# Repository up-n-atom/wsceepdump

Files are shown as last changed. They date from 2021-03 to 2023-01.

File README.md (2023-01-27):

# Just Enough WonderSwan Color/Swan Crystal EEPROM dumper

_⚠️ USE WITH CAUTION! Always test on a handheld of lesser importance to confirm its operation_

On each boot the bootrom writes to the EEPROM, removing the authenticity of the factory default. Such writes include the _"unique"_ cartridge count, boot count, and previously booted cartridge identifier. If these are not important, a custom rom and serial cable is the more convenient alternative, eg. https://github.com/asiekierka/ws-ieepview

> Fun Fact: The SwanCrystal EEPROM contains the Bandai bootsplash present in the bootrom.

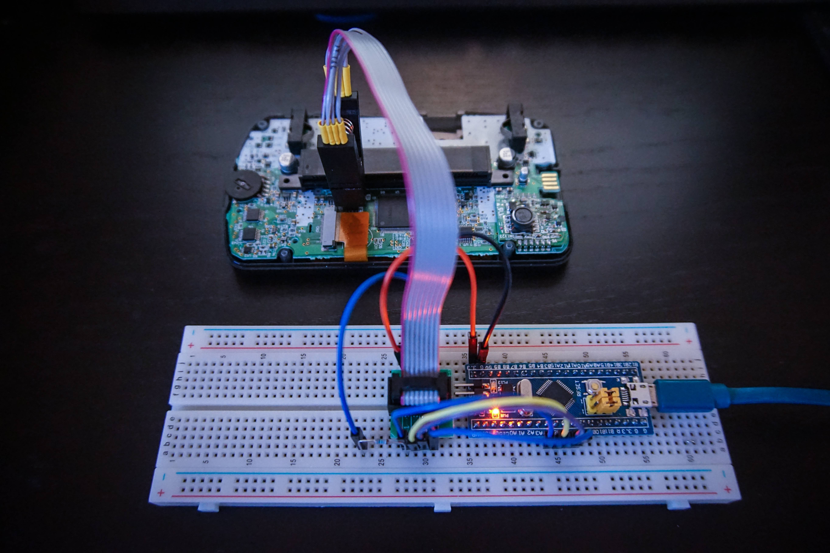
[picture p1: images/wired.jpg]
Wired


## Components

> Shop around, AliExpress links are non-affiliated top searches.

* 1x Blue Pill [[AliExpress](https://www.aliexpress.com/item/32792513237.html)]
* 1x ST-Link<sup>1</sup> or USB to TTL<sup>2</sup> [[AliExpress<sup>1</sup>](https://www.aliexpress.com/item/32887597480.html) or [AliExpress<sup>2</sup>](https://www.aliexpress.com/item/32946781917.html)]
* 1x SOP8 Test Clip [[AliExpress](https://www.aliexpress.com/item/32968334401.html)]
* 1x Breadboard [[AliExpress](https://www.aliexpress.com/item/32430469610.html)]
* 7x Male to Male Dupont Cables [[AliExpress](https://www.aliexpress.com/item/4000203371860.html)]
* 1x 1.2K Resistor [[AliExpress](https://www.aliexpress.com/item/32847096736.html)]

## Arduino Bootloader

There are nemerous guides on how to install the STM32duino bootloader and the following [video](https://www.youtube.com/watch?v=Myon8H111PQ) does an excellent job of describing the process.

How to Install the STM32 USB Bootloader, New Version! \(Blue Pill F103C8T6\) (https://www.youtube.com/watch?v=Myon8H111PQ)

Additionally, you may require the [STM32 Virtual COM Port Driver](https://www.st.com/en/development-tools/stsw-stm32102.html).

## Wiring

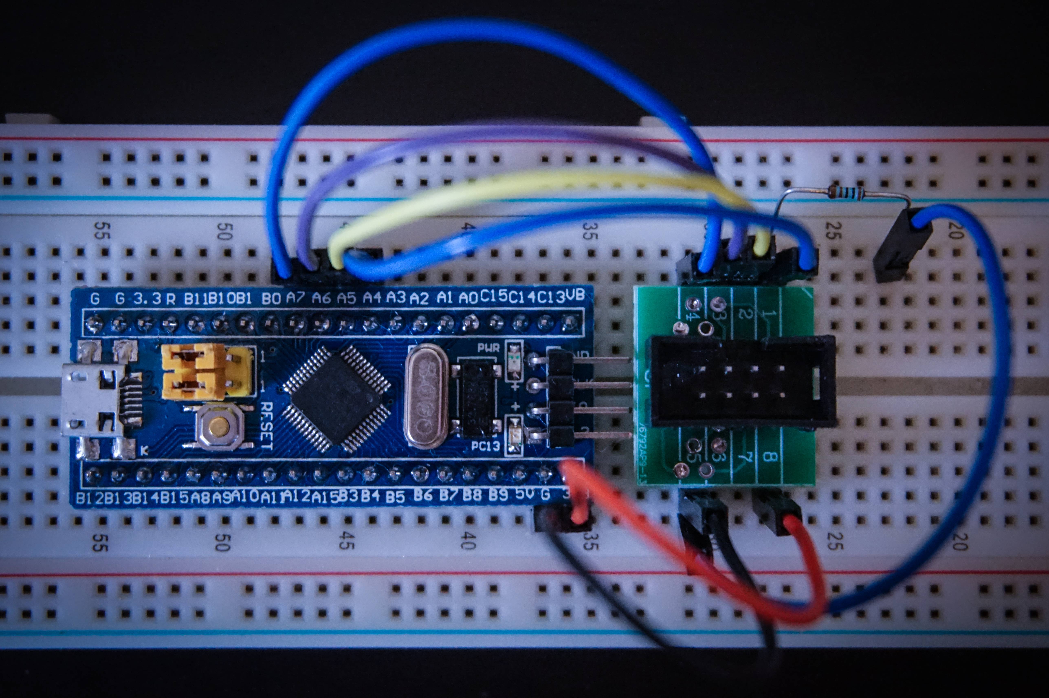
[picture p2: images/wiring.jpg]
Wiring


| Blue Pill | Test Clip | EEPROM |
|---|---|---|
| A4 | 1 | CS |
| A5 | 2 | SK |
| A6 | 3 | DI |
| A7 | 4 | DO |
| G | 5 | GND |
| 3.3 | 8 | VCC |

1.2K pull-down resistor connected to pin 1 (Chip Select) and pin 5 (Ground) of the test clip.

_Optional: 1.5K pull-up resistor connected to pin 4 (DO) and pin 8 (VCC) of the test clip._

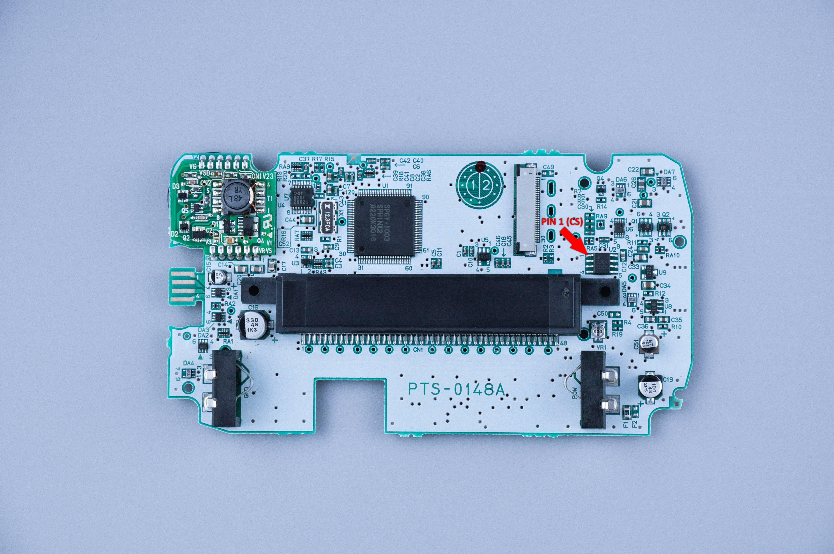
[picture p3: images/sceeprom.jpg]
SwanCrystal EEPROM


## Cape

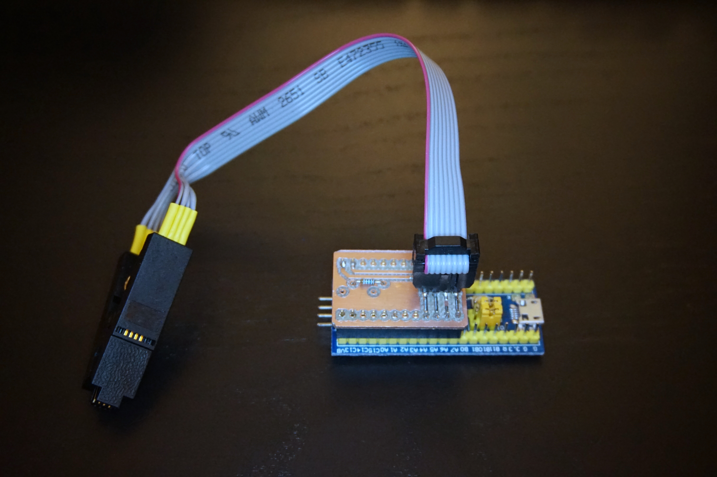
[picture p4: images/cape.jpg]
Blue Pill cape Blue Pill Cape


## Usage

1. Upload the [Arduino sketch](/arduino/wsc.ino) and run the Arduino IDE Serial Monitor or any alternative serial terminal such as [Tera Term](https://ttssh2.osdn.jp/index.html.en) or [Putty](https://www.putty.org/).
2. Send an **r** character to read the EEPROM.
3. Select all and copy the hex output.
4. Paste the copied hex output as _hex_ into a Hex Editor such as https://hexed.it/ or [HxD](https://mh-nexus.de/en/hxd/)
5. Save As...

## Testing

[Higan](https://higan.dev/) is able to load and emulate your EEPROM dump by renaming it as _save.eeprom_ and moving it into the _Systems/WonderSwan Color_ or _Systems/SwanCrystal_ directories.

## Custom Bootsplash

### WonderSwan Color

https://github.com/up-n-atom/higan/tree/ws-bootsplash/higan/System/WonderSwan%20Color

* [x] Dengeki
* [x] NAVI GET 400 Million
* [x] MS-06S Zaku II
* [x] RX-78-2
* [ ] Inuyasha
* [ ] Growlmon

### SwanCrystal

https://github.com/up-n-atom/higan/tree/ws-bootsplash/higan/System/SwanCrystal

* [x] One Piece Grand Battle Swan Colosseum 
* [ ] Tanita Mama Mitte

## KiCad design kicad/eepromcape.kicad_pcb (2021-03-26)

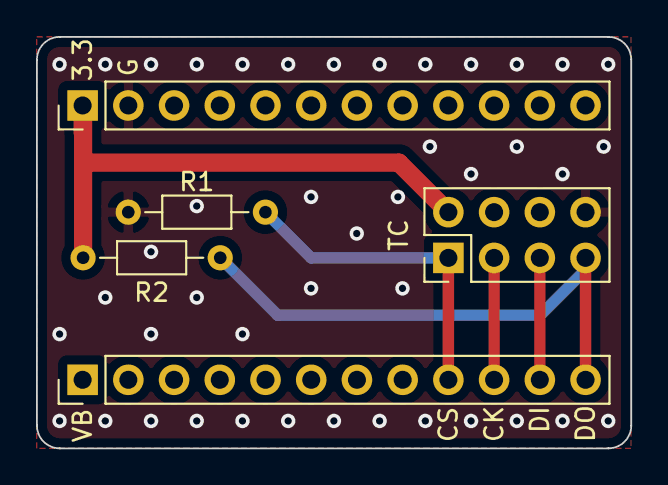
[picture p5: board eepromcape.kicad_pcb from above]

Board: 2 copper layers, 33.0 x 22.9 mm, 5 parts (1 on the bottom side), 6 nets.

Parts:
3.3: Conn_01x12; PinHeader_1x12_P2.54mm_Vertical
R1: 1K2; R_Axial_DIN0204_L3.6mm_D1.6mm_P7.62mm_Horizontal
R2: 1K5; R_Axial_DIN0204_L3.6mm_D1.6mm_P7.62mm_Horizontal
TC: Conn_02x04_Counter_Clockwise; PinSocket_2x04_P2.54mm_Vertical
VB: Conn_01x12; PinHeader_1x12_P2.54mm_Vertical

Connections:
+3V3: 3.3.1, R2.2, TC.8
CK: TC.2, VB.10
CS: R1.1, TC.1, VB.9
DI: TC.3, VB.11
DO: R2.1, TC.4, VB.12
GND: 3.3.2, R1.2, TC.5

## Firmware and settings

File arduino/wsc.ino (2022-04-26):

/* Forked from https://gist.github.com/krisha/fcaaf01534fa0ad9d3da

	Arduino code to read out and write EEPROM 93LC66
	which is used in an AEG 55GAD84AE induction hob.
	Some bits were flipped depending on temperature.
	Writing it back solved this problem.

	Modified for the STM32duino Blue Pill to read the
	WonderSwan Color/Swan Crystal.
*/

#define DELAY_MS 10

/* Bitbang using the SPI port of the Blue Pill. The
	STM32F103 natively supports the micro wire
	protocol on SPI, but where's the fun in that.
*/
#define CS PA4 /* A4 -> 1 */ 
#define CK PA5 /* A5 -> 2 */
#define DI PA6 /* A6 -> 3 */
#define DO PA7 /* A7 -> 4 */
/*	G   -> 5
	3.3 -> 8
	1.2K pull-down resistor on CS */

#define SZ 1024 /* EEPROM word size */

void spi_bit_tx ( uint8_t bit )
{
	digitalWrite ( DI, bit ? HIGH : LOW);
	digitalWrite ( CK, HIGH );
	delayMicroseconds ( DELAY_MS );
  
	digitalWrite ( CK, LOW );
	digitalWrite ( DI, LOW );
	delayMicroseconds ( DELAY_MS );
}

uint8_t spi_bit_rx ()
{
	uint8_t d;
  
	digitalWrite ( CK, HIGH );
	delayMicroseconds ( DELAY_MS );
  
	d = digitalRead ( DO );
  
	digitalWrite ( CK, LOW );
	delayMicroseconds ( DELAY_MS );
  
	return d ? 1 : 0;
}

void data_read2buf_bitbang ( uint16_t addr, uint16_t len, uint16_t *buf )
{
	int i, j;

	digitalWrite ( CS, HIGH );

	/* start bit */
	spi_bit_tx ( 1 );

	/* read opcode */
	spi_bit_tx ( 1 );
	spi_bit_tx ( 0 );

	/* address */
	for ( i = 9; i >= 0; i-- )
	{
		spi_bit_tx ( ( addr >> i ) & 1 );
	}

	/* continuous data */
	for ( i = 0; i < len; i++ )
	{
		for ( j = 0; j < 16; j++ )
		{
			buf[ i ] <<= 1;
			buf[ i ] |= spi_bit_rx ();
		}
	}

	digitalWrite ( CS, LOW );
}

void ewen_set_bitbang ()
{
	int i;
  
	digitalWrite ( CS, HIGH );
  
	spi_bit_tx ( 1 );
  
	spi_bit_tx ( 0 );
	spi_bit_tx ( 0 );
  
	for ( i = 0; i < 10; i++ )
		spi_bit_tx ( 1 );
  
	digitalWrite ( CS, LOW );
}

void data_write_bitbang ( uint16_t addr, uint16_t data )
{
	int i;
  
	digitalWrite ( CS, HIGH );
  
	spi_bit_tx ( 1 );
  
	spi_bit_tx ( 0 );
	spi_bit_tx ( 1 );
  
	for ( i = 9; i >= 0; i-- )
	{
		spi_bit_tx ( (addr >> i ) & 1 );
	}
  
	for ( i = 15; i >= 0; i-- )
	{
		spi_bit_tx ( (data >> i ) & 1 );
	}

	/* clock */
	digitalWrite ( CK, HIGH );
	delayMicroseconds ( DELAY_MS );
	digitalWrite ( CK, LOW );
	delayMicroseconds ( DELAY_MS );
  
	digitalWrite ( CS, LOW );
  
	/* clock */
	digitalWrite ( CK, HIGH );
	delayMicroseconds ( DELAY_MS );
	digitalWrite ( CK, LOW );
	delayMicroseconds ( DELAY_MS );
  
	digitalWrite ( CS, HIGH );
  
	/* clock 'til ready */
	digitalWrite ( CK, HIGH );
	delayMicroseconds ( DELAY_MS );
  
	while ( !digitalRead ( DO ) )
	{
		digitalWrite ( CK, LOW );
		delayMicroseconds ( DELAY_MS );
		digitalWrite ( CK, HIGH );
		delayMicroseconds ( DELAY_MS );
	}

	digitalWrite ( CK, LOW );
	delayMicroseconds ( DELAY_MS );
  
	digitalWrite ( CS, LOW );
}

void setup ()
{
	pinMode ( CS, OUTPUT );
	pinMode ( DI, OUTPUT );
	pinMode ( CK, OUTPUT );

	Serial.begin ( 115200 );
}

void loop ()
{
	uint16_t *buf;
	int i;
	char s [ 7 ] = { 0 };

	if ( Serial.available () > 0 )
	{
		switch ( Serial.read () )
		{
			case -1:
				break;
			case 'r':
				buf = (uint16_t *) calloc ( SZ, sizeof ( uint16_t ) );

				data_read2buf_bitbang ( 0, SZ, buf );

				for ( i = 0; i < SZ; i++ )
				{
					/* format as little endian */
					sprintf ( s, " %02X %02X", ( int )( buf[ i ] & 0xFF ), ( int )( buf[ i ] >> 8 ) );
					Serial.print ( s );
				}

				free ( buf );
				break;
		}
	}
}

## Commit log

2021-03-21 Add Arduino sketch
2021-03-25 Add KiCAD project
    [eepromcape.kicad_pcb, eepromcape.sch]
2021-03-25 Remove superfluous power traces
    [eepromcape.kicad_pcb]
2021-03-26 Fix 3D models
    [eepromcape.kicad_pcb]
